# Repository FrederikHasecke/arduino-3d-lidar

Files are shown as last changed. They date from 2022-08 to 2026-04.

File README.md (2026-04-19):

# Arduino 3D LiDAR

> [!IMPORTANT]
> Status: prototype. This repository documents a functional proof-of-concept with working firmware, printable parts, wiring references, sample data, and offline visualization tooling. Expect rough output, manual setup, and iteration rather than a polished product.

> [!NOTE]
> TL;DR: This project is a low-cost rotating 3D LiDAR built from 8 `VL53L0X` sensors, with firmware for Arduino/ESP32 and Python tools for offline visualization. It is useful for tinkering and rough room-scale mapping, but it is not a high-accuracy or high-fidelity LiDAR system.

If you are interested in longer-range sensors and not necessarily in 3D point cloud data, consider this alternative project: https://github.com/iliasam/OpenTOFLidar

## Overview
This repository contains the files needed to build a budget-friendly rotating 3D LiDAR sensor.
It combines 3D-printed parts, simple electronics, microcontroller firmware, sample recordings, and a lightweight Python viewer for inspecting captured point clouds.

Rotating LiDAR Sensor | LiDAR Data Visualization (5x Speed)
:---------------------:|:--------------------------:
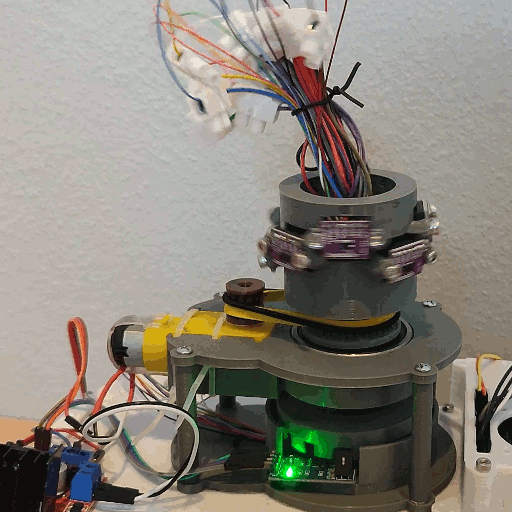
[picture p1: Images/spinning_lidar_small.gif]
Rotating LiDAR Sensor
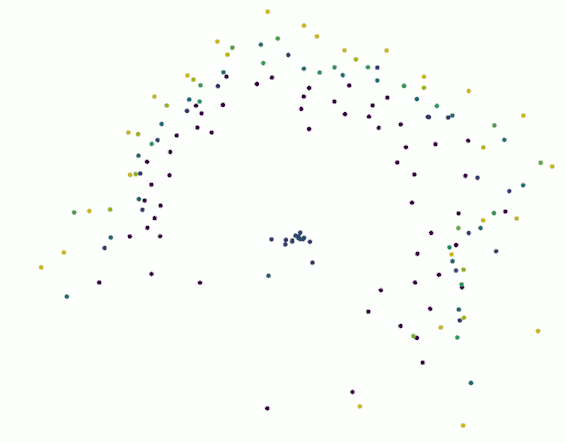
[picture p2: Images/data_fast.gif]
LiDAR Data Visualization
 | 

## Repository Contents
| Category | Path | Description |
|---|---|---|
| Firmware | `arduino-code/` | Arduino Uno firmware for the 8-sensor rotating scanner |
| Firmware | `esp32-code/` | ESP32 firmware variant for the same hardware concept |
| Python tools | `python-receiver-code/` | Offline visualization utilities for recorded `.npy` frames |
| 3D-print files | `stl-files/` | Printable mechanical parts plus assembly notes |
| Sample data | `data/sequences/01/lidar_points/` | Example recording for validating the Python viewer |
| Reference media | `Images/` | GIFs, wiring diagrams, and schematic images used in the docs |

## What This Project Is
- A low-cost 3D sensing prototype built from commodity time-of-flight sensors
- A hardware and firmware project that demonstrates multi-sensor scanning and reconstruction
- A practical tinkering platform for rough room-scale mapping and experimentation

## What This Project Is Not
- A drop-in replacement for a commercial LiDAR
- A precision point-cloud sensor for robotics or surveying workflows
- A polished product with enclosure, calibration workflow, and turnkey software

## How It Works
Eight `VL53L0X` range sensors are mounted on a rotating axis, each aimed at a different vertical angle toward a common origin. A rotation encoder at the base provides the azimuth angle. Combining range, vertical channel angle, and rotation angle makes it possible to reconstruct the scene in Cartesian coordinates.

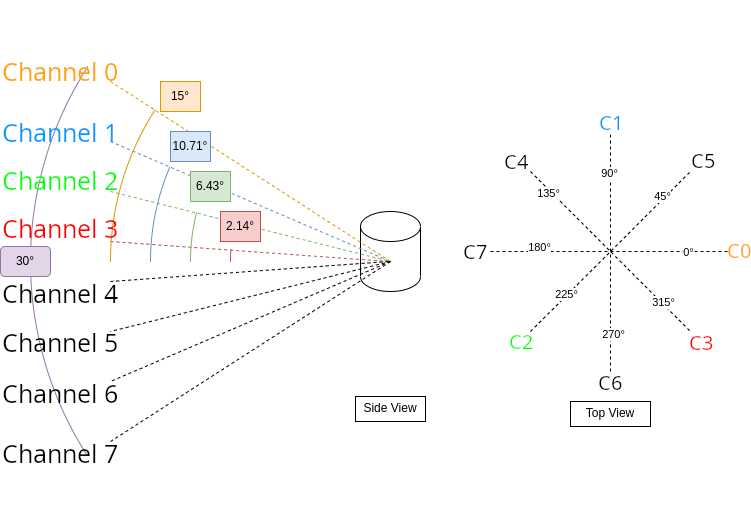
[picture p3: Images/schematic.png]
Schematic Drawing
|  |
| :-----------------------------------------: |
| *Schematic drawing of the mounting angles* |

The resulting point cloud is intentionally rough, but it is still useful for quick experiments such as room-scale occupancy mapping or basic spatial inspection.

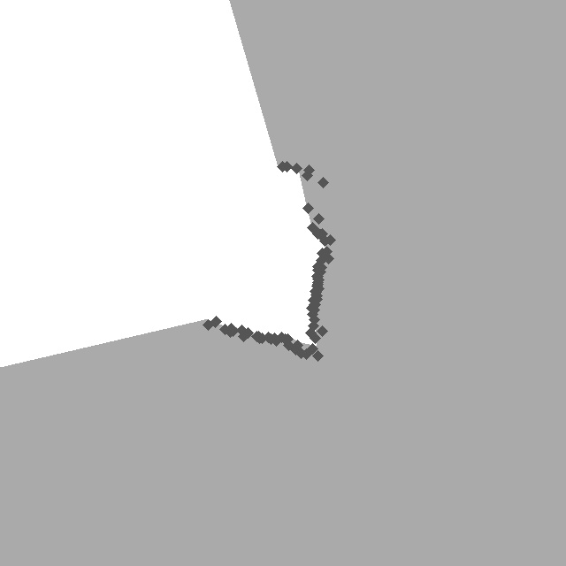
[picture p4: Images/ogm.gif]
Occupancy Grid Map using the LiDAR Sensor Data
|  |
| :---------------------------------------------------------------: |
| *Occupancy grid map generated from LiDAR sensor data (1x speed)* |

## Data Sample
The repository includes a sample recording in `data/sequences/01/lidar_points/` so you can inspect the expected output before building the hardware. Use `python-receiver-code/offline_visualization.py` to play back the bundled frames or your own recordings.

## Getting Started
1. Review the sample output.
   Check the GIFs above and the bundled `.npy` frames to understand the point-cloud quality you should expect.
2. Print the mechanical parts.
   Download the STL files from `stl-files/` and review `stl-files/assembly-instructions.md` for print orientation, wiring, and bring-up notes.
3. Choose a firmware target.
   Use `arduino-code/` for Arduino Uno or `esp32-code/` for ESP32. The wiring tables in the assembly guide match those firmware layouts.
4. Set up the Python viewer.
   The repository currently provides offline visualization for recorded `.npy` frames.

### Firmware Requirements
- Install the Arduino library `VL53L0X` by Pololu before compiling either firmware sketch.
- In Arduino IDE: `Sketch` -> `Include Library` -> `Manage Libraries...`, then search for `VL53L0X` and install the Pololu package.
- The ESP32 sketch in `esp32-code/` is updated for ESP32 Arduino core `3.x` timer APIs.

### Python Requirements
- Python `3.13+`
- `numpy`
- [VisPy](https://vispy.org/) for visualization
- [glfw](https://www.glfw.org/) as the lightweight windowing backend

### Install With `uv` (Recommended)

#### Windows:
```bash
powershell -ExecutionPolicy ByPass -c "irm https://astral.sh/uv/install.ps1 | iex"
uv python install 3.13
uv venv --python 3.13
.venv\Scripts\activate
uv sync
```

#### Linux/Mac:
```bash
curl -Ls https://astral.sh/uv/install.sh | sh
uv python install 3.13
uv venv --python 3.13
source .venv/bin/activate
uv sync
```

These commands use Python `3.13` as the default modern setup. If you already have another compatible interpreter installed, adjust the version accordingly.

### Install With `pip`
```bash
py -3.13 -m venv .venv
.venv\Scripts\activate
python -m pip install --upgrade pip
python -m pip install .
```

If you do not have Python `3.13` installed yet, replace `py -3.13` with any available compatible interpreter.

### Run the Offline Viewer
```bash
python python-receiver-code/offline_visualization.py
```

When no `--path` is provided, the script opens the bundled sample sequence from `data/sequences/01/lidar_points` and prints a disclaimer that the sample is intentionally rough.

The viewer uses a lightweight VisPy and GLFW window and loops until you close it, which makes it a quick install sanity check.

To visualize a different recording, pass either a single `.npy` frame or a directory of `.npy` frames:

```bash
python python-receiver-code/offline_visualization.py --path path\to\lidar_points
```

You can also adjust playback speed and marker size:

```bash
python python-receiver-code/offline_visualization.py --fps 4 --point-size 10
```

## Required Components
Below is a practical parts list for the 8-channel prototype. The Amazon links are non-affiliate example search links because exact listings change frequently.

| Part | Quantity | Notes | Amazon Link |
|---|---|---|---|
| `VL53L0X` breakout board | 8 | Use boards with accessible `XSHUT` pins for address reassignment | [Search](https://www.amazon.com/s?k=VL53L0X+breakout) |
| DC motor (3-12 V) | 1 | Use the ones with the yellow gear box | [Search](https://www.amazon.com/s?k=3-6+VDC+gear+motor) |
| Motor driver module | 1 | Any board compatible with your motor current and supply voltage (In doubt use L298N) | [Search](https://www.amazon.com/s?k=L298N+motor+driver) |
| Microcontroller | 1 | Arduino Uno or ESP32, depending on the firmware you plan to flash | [Search](https://www.amazon.com/s?k=Arduino+Uno+or+ESP32) |
| 12-wire slip ring | 1 | Carries power and signals through the rotating joint | [Search](https://www.amazon.com/s?k=12+wire+slip+ring) |
| Speed sensor / encoder module | 1 | Used to establish the rotation reference angle | [Search](https://www.amazon.com/s?k=LM393+speed+sensor+module) |
| Jumper wires | 1 set | Length depends on your mechanical layout | [Search](https://www.amazon.com/s?k=dupont+jumper+wires) |
| M3 screw assortment | 1 set | Verify lengths against your print tolerances and mounting choices | [Search](https://www.amazon.com/s?k=M3+screw+assortment) |
| Rubber band | 1 | Used in the current mechanical drive arrangement | [Search](https://www.amazon.com/s?k=rubber+bands) |

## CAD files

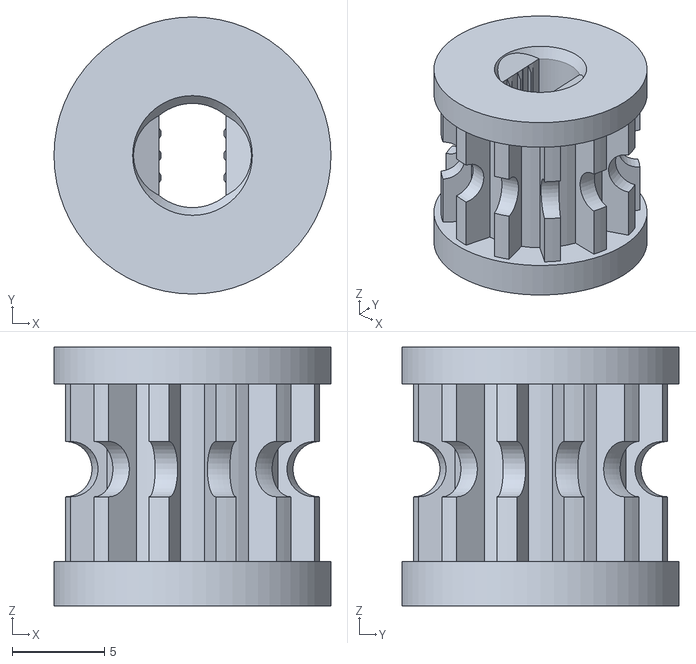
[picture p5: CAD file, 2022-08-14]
stl-files/small_gear_v0.6.stl
15.0 x 15.0 x 14.0

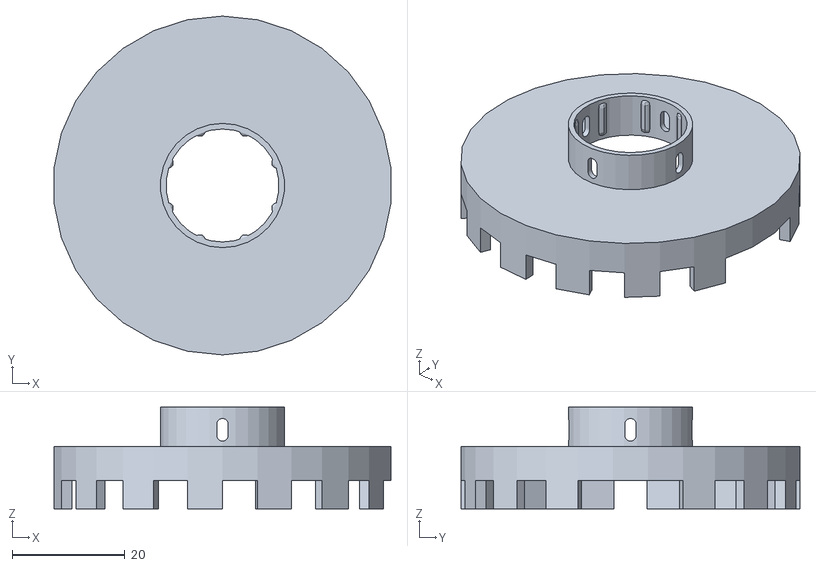
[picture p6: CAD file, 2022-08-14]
stl-files/encoder_v0.6.stl
59.7 x 60.0 x 18.0

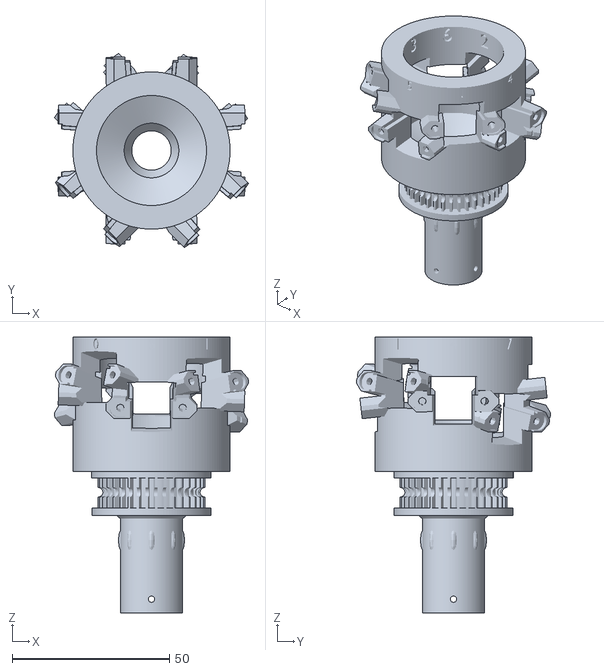
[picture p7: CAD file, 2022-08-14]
stl-files/head_v0.6.stl
61.9 x 61.9 x 87.8

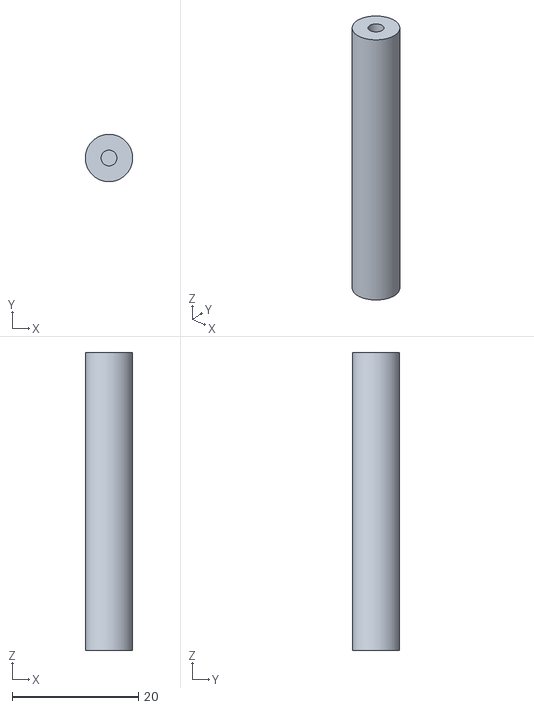
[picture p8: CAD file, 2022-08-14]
stl-files/single_pillar_v0.6.stl
7.50 x 7.50 x 47.2

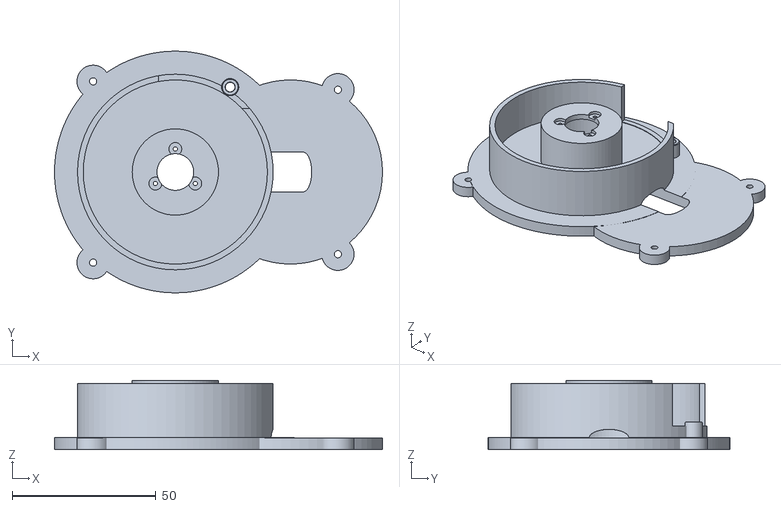
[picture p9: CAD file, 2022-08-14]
stl-files/base_bottom_v0.6.stl
114.0 x 84.0 x 24.0

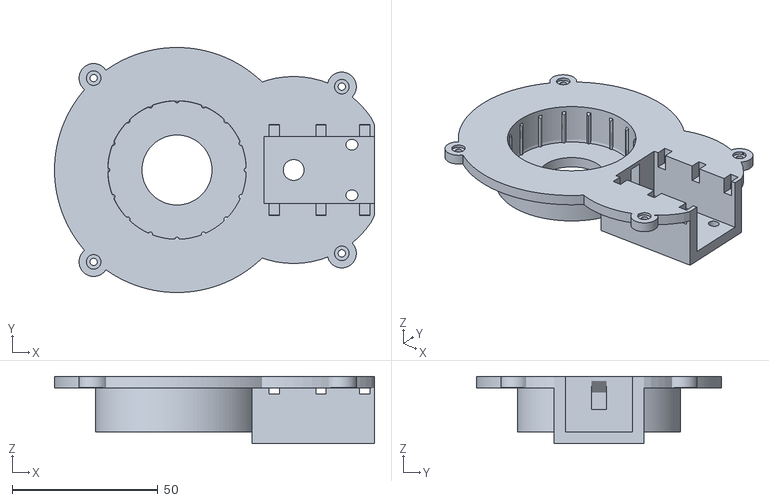
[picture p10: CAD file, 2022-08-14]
stl-files/base_top_v0.6.stl
109.7 x 84.0 x 23.0

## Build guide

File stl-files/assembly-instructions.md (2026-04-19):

# Assembly Instructions

This document covers print orientation, wiring, and first bring-up notes for the prototype.

## 1. Print the Parts

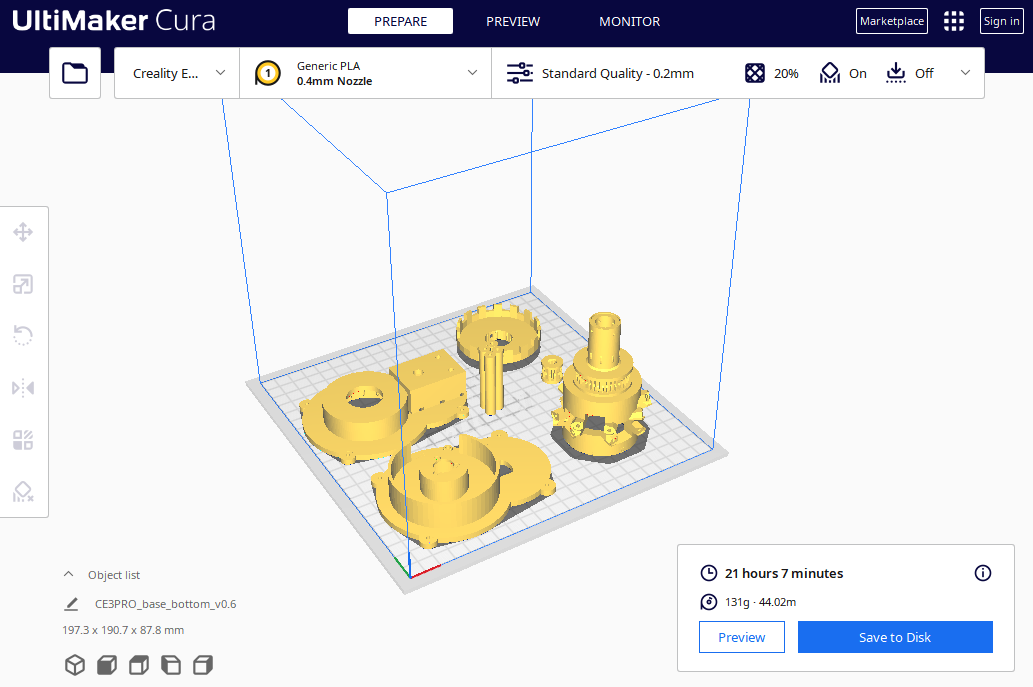
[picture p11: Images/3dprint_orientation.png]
Recommended Printing Orientation


- Print the STL files from `stl-files/`.
- Use the image above as the default print orientation reference.
- Layer height: 0.2mm or finer for better surface finish and dimensional accuracy.
- Infill: 20% or higher for structural integrity, especially for the rotating head and pillar.
- Supports: Enable supports for overhangs, particularly for the encoder mount and motor coupling features.
- Material: PLA is recommended for ease of printing and sufficient strength for prototyping. Consider PETG or ABS for improved durability and heat resistance if needed.

## 2. Mechanical Assembly

- Place slip ring on the shaft of the rotating head and secure it in the base top plate.
- Mount the motor top plate and secure it with zip ties. The gear box should fit snugly in the square cutout, and the motor shaft should align with the center hole.
- Mount the encoder disc on the shaft of the rotating head.
- Route the slip ring wires through the pillar and into the bottom base through the flat hole to the side of the base for connection to the `Arduino` or `ESP32`.
- Now add the pillars to the top and bottom base plates and secure them with screws.
- Add the small gear to the motor shaft.
- Connect the gear of the motor shaft and the rotating head with a rubber band or O-ring. Adjust the tension as needed for smooth rotation without slipping.
- Add the `VL53L0X` sensors to the sensor mounts on the rotating head, ensuring that the sensor faces are oriented correctly for distance measurement.
- Follow the wiring diagrams in sections 3 and 4 to connect the sensors, motor driver, and encoder to the `Arduino Uno` or `ESP32`.
- Secure the sensors with screws or adhesive as needed, ensuring that the sensor faces are flush with the outer surface of the rotating head for accurate measurements.

## 3. Arduino Uno Wiring

This wiring layout matches `arduino-code/write_byte_output_batchwise.ino`

> [!CAUTION]
> `VL53L0X` `XSHUT` is not 5 V tolerant. Driving it directly from 5 V can damage the sensor.

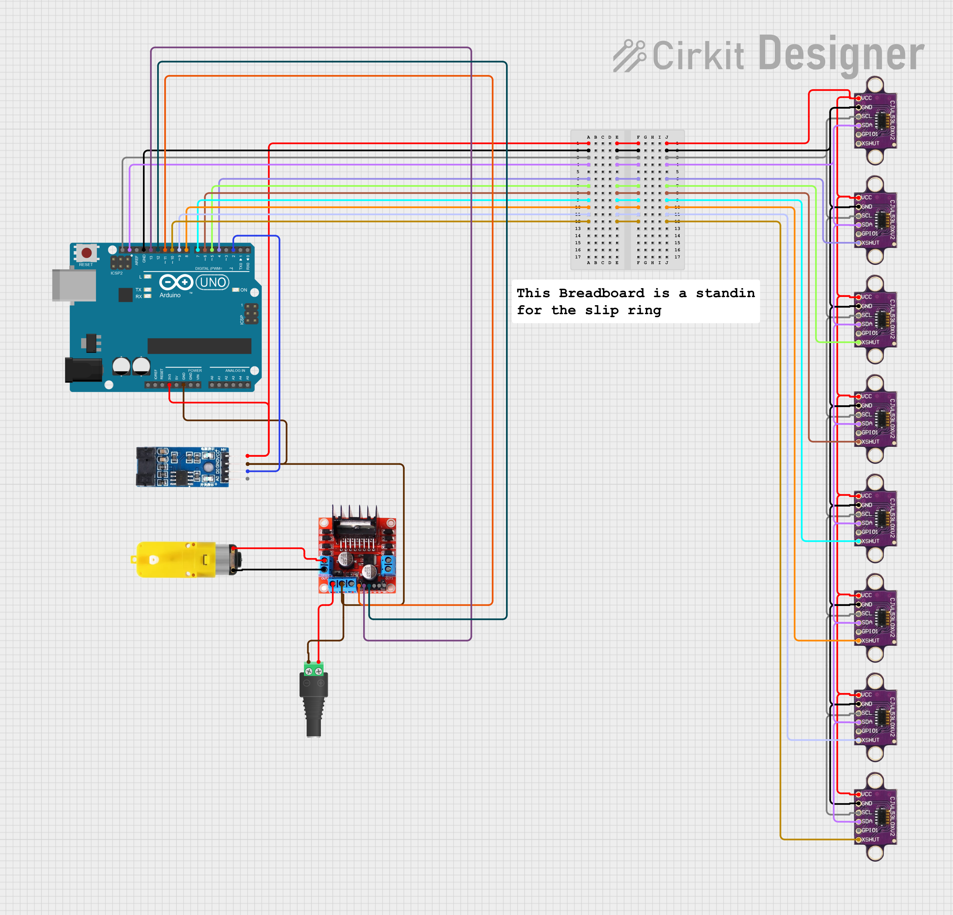
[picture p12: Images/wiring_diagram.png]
Arduino Uno wiring diagram


Function | Arduino pin | Notes
---------|-------------|------
`VL53L0X` Sensor 0 `XSHUT` | not used in code | Sensor 0 stays on the default I2C address `41`
`VL53L0X` Sensor 1 `XSHUT` | 4 | Reassigned to I2C address `42`
`VL53L0X` Sensor 2 `XSHUT` | 5 | Reassigned to I2C address `43`
`VL53L0X` Sensor 3 `XSHUT` | 6 | Reassigned to I2C address `44`
`VL53L0X` Sensor 4 `XSHUT` | 7 | Reassigned to I2C address `45`
`VL53L0X` Sensor 5 `XSHUT` | 8 | Reassigned to I2C address `46`
`VL53L0X` Sensor 6 `XSHUT` | 9 | Reassigned to I2C address `47`
`VL53L0X` Sensor 7 `XSHUT` | 10 | Reassigned to I2C address `48`
Motor driver enable `enA` | 11 | PWM speed control
Motor driver input `in1` | 12 | Direction control
Motor driver input `in2` | 13 | Direction control
Rotation encoder output | 2 | Interrupt input on rising edge
USB serial | `Serial` at `115200` | Data output to host computer

## 4. ESP32 Wiring

This wiring layout matches `esp32-code/write_byte_output_batchwise_esp32.ino`

> [!CAUTION]
> `VL53L0X` `XSHUT` is not 5 V tolerant. Confirm that your wiring and sensor boards stay within the correct logic voltage range.

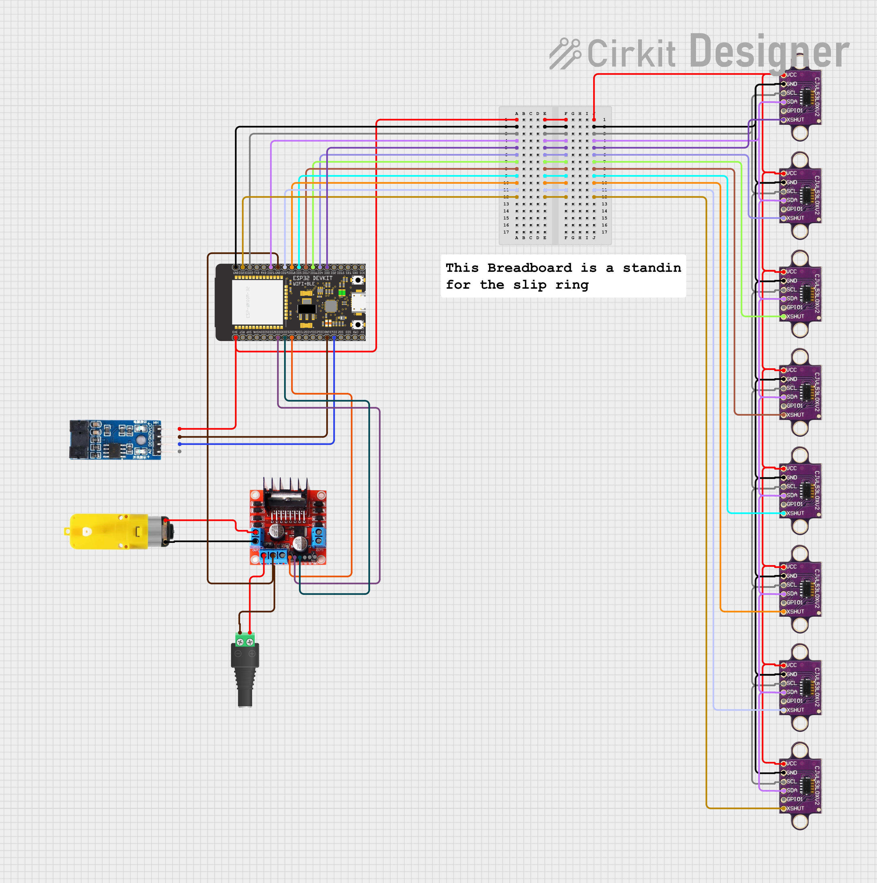
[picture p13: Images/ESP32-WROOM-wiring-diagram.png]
ESP32 wiring diagram


Function | ESP32 pin | Notes
---------|-----------|------
`VL53L0X` Sensor 0 `XSHUT` | 0 | Reassigned to I2C address `42`
`VL53L0X` Sensor 1 `XSHUT` | 4 | Reassigned to I2C address `43`
`VL53L0X` Sensor 2 `XSHUT` | 16 | Reassigned to I2C address `44`
`VL53L0X` Sensor 3 `XSHUT` | 17 | Reassigned to I2C address `45`
`VL53L0X` Sensor 4 `XSHUT` | 5 | Reassigned to I2C address `46`
`VL53L0X` Sensor 5 `XSHUT` | 18 | Reassigned to I2C address `47`
`VL53L0X` Sensor 6 `XSHUT` | 19 | Reassigned to I2C address `48`
`VL53L0X` Sensor 7 `XSHUT` | 23 | Sensor 7 stays on the default I2C address `41`
Motor driver enable `enA` | 25 | PWM speed control
Motor driver input `in1` | 33 | Direction control
Motor driver input `in2` | 32 | Direction control
Rotation encoder output | 13 | Interrupt input on rising edge
USB serial | `Serial` at `115200` | Data output to host computer

## 5. Pre-Power Checklist

- Verify that every `VL53L0X` `XSHUT` line is wired to the intended pin.
- Verify that no `XSHUT` pin is exposed to 5 V.
- Verify motor driver polarity before running the rotating assembly.
- Verify the encoder output pin before relying on angle synchronization.
- Confirm that the flashed firmware matches the wiring table you used.
- Make sure that the motor and the board is powered via their respective power inputs, and not just through USB. This is especially important for the `ESP32` which may draw more current than the USB port can provide when the motor is running. 

## 6. Bring-Up Notes

- If the point cloud data is not appearing on the host computer, check the serial output for error messages or invalid readings.
- If the motor is not spinning, check the motor driver connections and ensure that the enable pin is receiving the correct PWM signal.
- If the encoder readings are erratic, check the wiring and ensure that the encoder disc is properly mounted and aligned with the sensor.
- If the resulting point cloud is mis-aligned or distorted, verify that the motor spin direction matches the expected direction in the code, else the angle calculations will be inverted. Switch the motor driver input pins if needed to correct the direction.

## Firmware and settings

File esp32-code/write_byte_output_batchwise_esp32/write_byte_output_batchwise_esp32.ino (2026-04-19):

#include <Arduino.h>
#include "esp_timer.h"
#include <Wire.h>
#include <VL53L0X.h>

 
#define XSHUT_pin7 23  // N/A for Arduino         // Cable colors lightBlue-Blue
#define XSHUT_pin6 19  //9                        // Cable colors White-White
#define XSHUT_pin5 18  //8                        // Cable colors Brown-Brown
#define XSHUT_pin4 5   //7                        // Cable colors Orange-Orange
#define XSHUT_pin3 17  //6                        // Cable colors Yellow-Yellow
#define XSHUT_pin2 16  //5                        // Cable colors Green-LightGreen
#define XSHUT_pin1 4   //4                        // Cable colors Blue-Blue
#define XSHUT_pin0 0    

//ADDRESS_DEFAULT 0b0101001 or 41
#define Sensor0_newAddress 42 
#define Sensor1_newAddress 43 
#define Sensor2_newAddress 44
#define Sensor3_newAddress 45
#define Sensor4_newAddress 46
#define Sensor5_newAddress 47
#define Sensor6_newAddress 48
#define Sensor7_newAddress 41

VL53L0X Sensor0;
VL53L0X Sensor1;
VL53L0X Sensor2;
VL53L0X Sensor3;
VL53L0X Sensor4;
VL53L0X Sensor5;
VL53L0X Sensor6;
VL53L0X Sensor7;

// Define Motor Pins
#define enA 25 // analog output (Uno: 11 / ESP32: 25
#define in1 33 // digital output (Uno: 12 / ESP32: 33 (über 25)
#define in2 32 // digital output (Uno: 13 / ESP32: 32 (über 33)
int pinEncoderPos = 13; //Uno: 2; // digital sensor input

//Define Variables we'll be connecting to
int motor_power = 150; //original motor power
int goal_mspr = 500; // we want two rotations per second
volatile int mspr; // ms per rotation

// Lidar distance variables for each channel
int dist0;
int dist1;
int dist2;
int dist3;
int dist4;
int dist5;
int dist6;
int dist7;

// Lidar sensor angle variables for each channel
int angle0;
int angle1;
int angle2;
int angle3;
int angle4;
int angle5;
int angle6;
int angle7;

int max_range = 3000;

// for the interupt
volatile int angle = 0;
volatile float ratio = 0;
volatile bool zeroPos = false;
volatile bool tick = false;
volatile int tickDurationLastTime = 10;
volatile int tickAngle = 0;
volatile int tickLastTime = 0;
volatile int msLastTime = 0;

//// Timer 
hw_timer_t * timer = NULL;
portMUX_TYPE timerMux = portMUX_INITIALIZER_UNLOCKED;

//############################################
//##           EXTRA FUNCTIONS              ##
//############################################
void onTimer(){
  angle++; // set to next angle step
}

// Only triggered when switch High->Low (so if a tooth comes into view) (gap is HIGH)
void IRAM_ATTR encoderTick(){
    volatile unsigned long ms = millis();
    volatile int tickDuration = ms-tickLastTime;   // compute transition time 

    // This is a hardcoded value depending on the 2Hz frequency, adjust accordinly for slower or faster rotations
    if (2*tickDuration>3*tickDurationLastTime && tickDuration>50){
        zeroPos = true;
        tickAngle = 0;     // reset angle to zero    
        angle = tickAngle;

        mspr = ms-msLastTime; // Milliseconds per rotations

        msLastTime = ms;
    } else {
      tickAngle+=24; // 360deg divided by the "15" teeth
      angle = tickAngle; // We are at a tooth, so pull the angle                       
    }
    tickLastTime = ms; // remember transition time  
    tickDurationLastTime = tickDuration; // remember duration time
}

//############################################
//##               SETUP                    ##
//############################################
void setup() 
{
  /*WARNING*/
  //Shutdown pins of VL53L0X ACTIVE-LOW-ONLY NO TOLERANT TO 5V will fry them
  pinMode(XSHUT_pin0, OUTPUT);
  pinMode(XSHUT_pin1, OUTPUT);
  pinMode(XSHUT_pin2, OUTPUT);
  pinMode(XSHUT_pin3, OUTPUT);
  pinMode(XSHUT_pin4, OUTPUT);
  pinMode(XSHUT_pin5, OUTPUT);
  pinMode(XSHUT_pin6, OUTPUT);
  pinMode(XSHUT_pin7, OUTPUT); 

  //Motor
  pinMode(enA, OUTPUT); //PWM for rotation speed
  pinMode(in1, OUTPUT);
  pinMode(in2, OUTPUT);

  // Serial Output
  Serial.begin(115200);

  // Rotation encoder
  pinMode (pinEncoderPos, INPUT); 

  // start I2C for lidars
  Wire.begin();

  //Change address of sensor and power up next one  
  Sensor7.setAddress(Sensor7_newAddress);
  pinMode(XSHUT_pin7, INPUT);
  delay(10); //For power-up procedure t-boot max 1.2ms "Datasheet: 2.9 Power sequence"
  
  Sensor6.setAddress(Sensor6_newAddress);
  pinMode(XSHUT_pin6, INPUT);
  delay(10); //For power-up procedure t-boot max 1.2ms "Datasheet: 2.9 Power sequence"  
  
  Sensor5.setAddress(Sensor5_newAddress);
  pinMode(XSHUT_pin5, INPUT);
  delay(10); //For power-up procedure t-boot max 1.2ms "Datasheet: 2.9 Power sequence"

  Sensor4.setAddress(Sensor4_newAddress);
  pinMode(XSHUT_pin4, INPUT);
  delay(10); //For power-up procedure t-boot max 1.2ms "Datasheet: 2.9 Power sequence"
  
  Sensor3.setAddress(Sensor3_newAddress);
  pinMode(XSHUT_pin3, INPUT);
  delay(10); //For power-up procedure t-boot max 1.2ms "Datasheet: 2.9 Power sequence"

  Sensor2.setAddress(Sensor2_newAddress);
  pinMode(XSHUT_pin2, INPUT);
  delay(10); //For power-up procedure t-boot max 1.2ms "Datasheet: 2.9 Power sequence"

  Sensor1.setAddress(Sensor1_newAddress);
  pinMode(XSHUT_pin1, INPUT);
  delay(10); //For power-up procedure t-boot max 1.2ms "Datasheet: 2.9 Power sequence"

  Sensor0.setAddress(Sensor0_newAddress);
  pinMode(XSHUT_pin0, INPUT);
  delay(10); //For power-up procedure t-boot max 1.2ms "Datasheet: 2.9 Power sequence"


  Sensor0.init();
  Sensor1.init();
  Sensor2.init();
  Sensor3.init();
  Sensor4.init();
  Sensor5.init();
  Sensor6.init();
  Sensor7.init();

  Sensor0.setMeasurementTimingBudget(20000);
  Sensor1.setMeasurementTimingBudget(20000);
  Sensor2.setMeasurementTimingBudget(20000);
  Sensor3.setMeasurementTimingBudget(20000);
  Sensor4.setMeasurementTimingBudget(20000);
  Sensor5.setMeasurementTimingBudget(20000);
  Sensor6.setMeasurementTimingBudget(20000);
  Sensor7.setMeasurementTimingBudget(20000);


  // Lets use a timeout
  Sensor0.setTimeout(0);
  Sensor1.setTimeout(0);
  Sensor2.setTimeout(0);
  Sensor3.setTimeout(0);
  Sensor4.setTimeout(0);
  Sensor5.setTimeout(0);
  Sensor6.setTimeout(0);
  Sensor7.setTimeout(0);

  
  // Start continuous back-to-back mode (take readings as
  // fast as possible).  To use continuous timed mode
  // instead, provide a desired inter-measurement period in
  // ms (e.g. sensor.startContinuous(100)).
  Sensor0.startContinuous(10); // do not change to zero, ESP32 tends to hang infinitely when changed to zero
  Sensor1.startContinuous(10);
  Sensor2.startContinuous(10);
  Sensor3.startContinuous(10);
  Sensor4.startContinuous(10);
  Sensor5.startContinuous(10);
  Sensor6.startContinuous(10);
  Sensor7.startContinuous(10);

  // Start Spinning Motor
  digitalWrite(in1, LOW);
  digitalWrite(in2, HIGH);

  // ESP32 core 3.x uses the new timer API. Use a 1 MHz timer so the
  // alarm value remains in microseconds like the original sketch.
  timer = timerBegin(1000000);
  timerAttachInterrupt(timer, &onTimer);
  timerAlarm(timer, 1389, true, 0); // 720deg in 1 second, so 1 deg every 1/720 sec

  // Attach the interupt for rotation encoder
  attachInterrupt(pinEncoderPos, encoderTick, RISING);

  // init at half speed
  analogWrite(enA, motor_power); // 0-255
  delay(200); // give some time before starting just in case
}

//############################################
//##               MAIN LOOP                ##
//############################################

void loop()
{

  // if the encoder defined the zero degree position
  if (zeroPos){
  
      zeroPos = false;

      // send the zero sync
      Serial.write(254); // START Codon 1
      Serial.write(253); // START Codon 2

      Serial.write(0xFF);
      Serial.write(0xFF);
      Serial.write(0xFF);
      Serial.write(0xFF);
      
      Serial.write(0xFF);
      Serial.write(0xFF);
      Serial.write(0xFF);
      Serial.write(0xFF);

      Serial.write(0xFF);
      Serial.write(0xFF);
      Serial.write(0xFF);
      Serial.write(0xFF);
      
      Serial.write(0xFF);
      Serial.write(0xFF);
      Serial.write(0xFF);
      Serial.write(0xFF);
      
      Serial.write(0xFF);
      Serial.write(0xFF);
      Serial.write(0xFF);
      Serial.write(0xFF);
      
      Serial.write(0xFF);
      Serial.write(0xFF);
      Serial.write(0xFF);
      Serial.write(0xFF);
      
      Serial.write(0xFF);
      Serial.write(0xFF);
      Serial.write(0xFF);
      Serial.write(0xFF);
      
      Serial.write(0xFF);
      Serial.write(0xFF);
      Serial.write(0xFF);
      Serial.write(0xFF);
      
      Serial.write(252); // END Codon 1
      Serial.write(251); // END Codon 2
      Serial.flush();    

      if(mspr>goal_mspr+5){ // we take too long for one rotation, speed up
        motor_power++;
      }
      else if(mspr<goal_mspr-5){ // we take too short for one rotation, slow down
        motor_power--;
      }
      analogWrite(enA, int(motor_power)); 

          
  }

  dist0 = Sensor7.readRangeContinuousMillimeters();
  if (Sensor7.timeoutOccurred()) { dist0 = 0; }
  angle0 = angle;

  dist1 = Sensor0.readRangeContinuousMillimeters();
  if (Sensor0.timeoutOccurred()) { dist1 = 0; }
  angle1 = angle;

  dist2 = Sensor1.readRangeContinuousMillimeters();
  if (Sensor1.timeoutOccurred()) { dist2 = 0; }
  angle2 = angle;

  dist3 = Sensor2.readRangeContinuousMillimeters();
  if (Sensor2.timeoutOccurred()) { dist3 = 0; }
  angle3 = angle;

  dist4 = Sensor3.readRangeContinuousMillimeters();
  if (Sensor3.timeoutOccurred()) { dist4 = 0; }
  angle4 = angle;

  dist5 = Sensor4.readRangeContinuousMillimeters();
  if (Sensor4.timeoutOccurred()) { dist5 = 0; }
  angle5 = angle;

  dist6 = Sensor5.readRangeContinuousMillimeters();
  if (Sensor5.timeoutOccurred()) { dist6 = 0; }
  angle6 = angle;

  dist7 = Sensor6.readRangeContinuousMillimeters();
  if (Sensor6.timeoutOccurred()) { dist7 = 0; }
  angle7 = angle;


  // Values over max_range are unreliable, set to defined max range
  if (dist0 > max_range){dist0=max_range;}
  if (dist1 > max_range){dist1=max_range;}
  if (dist2 > max_range){dist2=max_range;}
  if (dist3 > max_range){dist3=max_range;}
  if (dist4 > max_range){dist4=max_range;}
  if (dist5 > max_range){dist5=max_range;}
  if (dist6 > max_range){dist6=max_range;}
  if (dist7 > max_range){dist7=max_range;}

  Serial.write(254); // START Codon 1
  Serial.write(253); // START Codon 2

  // Angle and Distance can be higher than 255, we need two bytes to send the values
  // split the values into the upper and lower bytes, send them in a fixed order

  Serial.write(angle0 >> 8);
  Serial.write(angle0 & 0xFF);    
  Serial.write(dist0 >> 8);  
  Serial.write(dist0 & 0xFF);    

  Serial.write(angle1 >> 8);  
  Serial.write(angle1 & 0xFF);    
  Serial.write(dist1 >> 8);  
  Serial.write(dist1 & 0xFF);     

  Serial.write(angle2 >> 8);  
  Serial.write(angle2 & 0xFF);    
  Serial.write(dist2 >> 8);  
  Serial.write(dist2 & 0xFF);  

  Serial.write(angle3 >> 8);  
  Serial.write(angle3 & 0xFF);    
  Serial.write(dist3 >> 8);  
  Serial.write(dist3 & 0xFF);  

  Serial.write(angle4 >> 8);  
  Serial.write(angle4 & 0xFF);    
  Serial.write(dist4 >> 8);  
  Serial.write(dist4 & 0xFF);       

  Serial.write(angle5 >> 8);  
  Serial.write(angle5 & 0xFF);    
  Serial.write(dist5 >> 8);  
  Serial.write(dist5 & 0xFF);   

  Serial.write(angle6 >> 8);  
  Serial.write(angle6 & 0xFF);    
  Serial.write(dist6 >> 8);  
  Serial.write(dist6 & 0xFF);    

  Serial.write(angle7 >> 8);  
  Serial.write(angle7 & 0xFF);    
  Serial.write(dist7 >> 8);  
  Serial.write(dist7 & 0xFF);    

  Serial.write(252); // END Codon 1
  Serial.write(251); // END Codon 2       
  Serial.flush();  
}

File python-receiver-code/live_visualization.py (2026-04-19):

"""Live point-cloud visualization for the Arduino/ESP32 LiDAR serial stream."""

from __future__ import annotations

import argparse
import queue
import threading
from pathlib import Path

import numpy as np

from offline_visualization import (
    ORIGIN_LINE_COLORS,
    ORIGIN_MARKER_COLOR,
    convert_to_cartesian,
    load_vispy_modules,
    origin_axis_segments,
    point_colors,
)
from receive_data import FrameAccumulator, SerialPacketReader, open_serial_connection, resolve_output_dir, save_frame


DEFAULT_BAUD = 115200
DEFAULT_REFRESH_HZ = 30.0


def parse_args() -> argparse.Namespace:
    parser = argparse.ArgumentParser(
        description="Live-visualize LiDAR frames from the Arduino/ESP32 serial stream."
    )
    parser.add_argument("--port", required=True, help="Serial port, e.g. COM3 or /dev/ttyUSB0.")
    parser.add_argument(
        "--baud",
        type=int,
        default=DEFAULT_BAUD,
        help=f"Serial baud rate. Defaults to {DEFAULT_BAUD}.",
    )
    parser.add_argument(
        "--serial-timeout",
        type=float,
        default=0.25,
        help="Serial read timeout in seconds. Defaults to 0.25.",
    )
    parser.add_argument(
        "--point-size",
        type=float,
        default=8.0,
        help="Point size in screen pixels. Defaults to 8.0.",
    )
    parser.add_argument(
        "--save",
        action="store_true",
        help="Save every completed frame to disk while visualizing.",
    )
    parser.add_argument(
        "--output-dir",
        type=Path,
        help="Directory to save timestamped .npy frames into when --save is used.",
    )
    return parser.parse_args()


class SerialFrameWorker(threading.Thread):
    def __init__(
        self,
        serial_connection,
        frame_queue: queue.SimpleQueue[tuple[np.ndarray, Path | None]],
        output_dir: Path | None,
    ) -> None:
        super().__init__(daemon=True)
        self._serial_connection = serial_connection
        self._frame_queue = frame_queue
        self._output_dir = output_dir
        self._stop_event = threading.Event()
        self._accumulator = FrameAccumulator()
        self.error: Exception | None = None

    def stop(self) -> None:
        self._stop_event.set()

    def run(self) -> None:
        try:
            packet_reader = SerialPacketReader(self._serial_connection)
            while not self._stop_event.is_set():
                packet = packet_reader.read_packet(stop_event=self._stop_event)
                if packet is None:
                    continue

                frame = self._accumulator.add_packet(packet)
                if frame is None:
                    continue

                frame_path = None
                if self._output_dir is not None:
                    frame_path = save_frame(frame, self._output_dir)
                self._frame_queue.put((frame, frame_path))
        except Exception as exc:  # pragma: no cover - runtime error reporting path
            self.error = exc
        finally:
            self._serial_connection.close()


class LivePointCloudViewer:
    def __init__(
        self,
        worker: SerialFrameWorker,
        frame_queue: queue.SimpleQueue[tuple[np.ndarray, Path | None]],
        point_size: float,
    ) -> None:
        if point_size <= 0:
            raise ValueError("--point-size must be greater than 0.")

        app, scene = load_vispy_modules()
        self._app = app
        self._worker = worker
        self._frame_queue = frame_queue
        self._point_size = point_size
        self._frame_count = 0
        self._latest_saved_path: Path | None = None
        self._bounds_min: np.ndarray | None = None
        self._bounds_max: np.ndarray | None = None

        self.canvas = scene.SceneCanvas(
            title="Arduino 3D LiDAR Live Viewer",
            keys="interactive",
            bgcolor="#081018",
            size=(1280, 720),
            show=True,
        )
        self.view = self.canvas.central_widget.add_view()
        self.view.camera = scene.cameras.TurntableCamera(
            fov=45.0,
            azimuth=35.0,
            elevation=20.0,
            center=(0.0, 0.0, 0.0),
            scale_factor=5.0,
        )

        self.markers = scene.visuals.Markers(parent=self.view.scene)
        self.markers.set_gl_state(
            depth_test=True,
            blend=True,
            blend_func=("src_alpha", "one_minus_src_alpha"),
        )
        self.origin_marker = scene.visuals.Markers(parent=self.view.scene)
        self.origin_marker.set_gl_state(
            depth_test=True,
            blend=True,
            blend_func=("src_alpha", "one_minus_src_alpha"),
        )
        self.origin_axes = scene.visuals.Line(
            parent=self.view.scene,
            connect="segments",
            width=2.0,
            method="gl",
        )
        self._configure_origin(axis_length=0.2)

        self.timer = app.Timer(interval=1.0 / DEFAULT_REFRESH_HZ, connect=self._on_timer, start=True)
        self.canvas.events.close.connect(self._on_close)

    def _configure_origin(self, axis_length: float) -> None:
        self.origin_marker.set_data(
            pos=np.zeros((1, 3), dtype=np.float32),
            face_color=ORIGIN_MARKER_COLOR,
            edge_color=np.array([[0.04, 0.04, 0.04, 1.0]], dtype=np.float32),
            edge_width=1.5,
            size=max(self._point_size * 1.75, 12.0),
            symbol="star",
        )
        self.origin_axes.set_data(pos=origin_axis_segments(axis_length), color=ORIGIN_LINE_COLORS)

    def _apply_camera_bounds(self) -> None:
        if self._bounds_min is None or self._bounds_max is None:
            return

        center = (self._bounds_min + self._bounds_max) / 2.0
        size = np.maximum(self._bounds_max - self._bounds_min, 0.1)
        padding = np.maximum(size * 0.15, 0.1)
        axis_length = float(max(np.max(size) * 0.08, 0.08))
        self._configure_origin(axis_length)

        self.view.camera.center = tuple(center.tolist())
        self.view.camera.scale_factor = float(np.max(size + padding) * 1.6)
        self.view.camera.set_range(
            x=(float(self._bounds_min[0] - padding[0]), float(self._bounds_max[0] + padding[0])),
            y=(float(self._bounds_min[1] - padding[1]), float(self._bounds_max[1] + padding[1])),
            z=(float(self._bounds_min[2] - padding[2]), float(self._bounds_max[2] + padding[2])),
        )

    def _show_frame(self, raw_frame: np.ndarray, saved_path: Path | None) -> None:
        point_cloud = convert_to_cartesian(raw_frame)
        self.markers.set_data(
            pos=point_cloud,
            face_color=point_colors(point_cloud),
            edge_width=0.0,
            size=self._point_size,
            symbol="disc",
        )
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

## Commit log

2022-08-14 Added STL files and some more description to the readme.
    [base_bottom_v0.6.stl, base_top_v0.6.stl, encoder_v0.6.stl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]
2023-07-08 Added visualisation script
    [base_top_v0.6.stl, head_v0.6.stl, single_pillar_v0.6.stl]
2026-04-19 Added assembly instructions and wiring diagram https://github.com/FrederikHasecke/arduino-3d-lidar/issues/1
    [offline_visualization.py]
2026-10-09 Clamped motor PWM to 0-255 in both firmwares
    motor_power was adjusted every revolution without bounds. On the Uno,
    analogWrite wraps values above 255 to 0, so a slow motor would stop
    and the controller would keep increasing the value. Also marked the
    ESP32 timer ISR IRAM_ATTR and removed an unused mutex.
2026-10-09 Hid no-return points in viewers, simplified serial parser, added tests
    - Readings of 0 mm or clamped to 3000 mm are not surfaces but drew a
    phantom ring at 3 m (31% of the sample). Both viewers now skip them;
    --keep-invalid restores the old behaviour. Saved frames are unchanged.
    - Simplified the start-marker search in SerialPacketReader.
    - Shared the camera/origin setup between the live and offline viewers.
    - Added pytest tests for packet decoding, resync, frame assembly and
    coordinate conversion.
    - Added project metadata to pyproject.toml; ignored new recordings and
    caches.
2026-10-09 Rewrote README and added 6204-2RS bearing to the BOM
    Documented the serial capture and live viewer scripts, the .npy rame format and the serial packet layout. Added specifications measured from the sample recording and a limitations section. Fixed the pip and uv install steps and corrected the parts list.
2026-10-11 Added scan registration and map, replay and range-strip visuals
    render_readme_media.py turns a recording into a registered map of the
    surroundings (orbit GIF), a 2 Hz replay of the scan moving through that
    map, and an unrolled range-image strip. With --path it renders a user's
    own recording into a media/ folder next to it; without, it regenerates
    the README images from the bundled sample.
    The recordings contain spurious encoder ticks that rotate the rest of a
    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
2026-10-11 Updated BOM
2026-10-11 Improved README and fixed BOM total
    - Moved the hero GIFs up and added license, Python and board badges
    - Fixed the BOM total to match its rows (€128.78, ~€100 without
    filament, screws and jumper wires) and added a cost column
    - Showed the Uno and ESP32 wiring diagrams in the README
    - Added a section on running eight VL53L0X sensors on one I2C bus
    - Added an FAQ and a contributing section with improvement ideas
    - Re-encoded the hero GIF at 128 colours (3.7 MB -> 2.7 MB)
